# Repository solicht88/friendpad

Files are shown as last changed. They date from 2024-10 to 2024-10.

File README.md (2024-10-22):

# friendpad
My first ever PCB, created for Hack Club's YSWS [Hackpad](https://hackpad.hackclub.com/)!  
Designed to be used for 4 key rhythm games, as well as have enough keys to be used for shortcuts or as a midi controller.  
There was an attempt to make something resembling a friendly face by placing rotary encoders (eyes) on both sides of the OLED (mouth).  
I started this project as a small simple macropad, but then it somehow grew to this

### Acknowledgements:  
[KiCad](https://www.kicad.org/)  
[Shapr3D](https://www.shapr3d.com/)  
[ScottoKeebs Kicad Footprint Collection](https://github.com/joe-scotto/scottokeebs/tree/main/Extras/ScottoKicad)

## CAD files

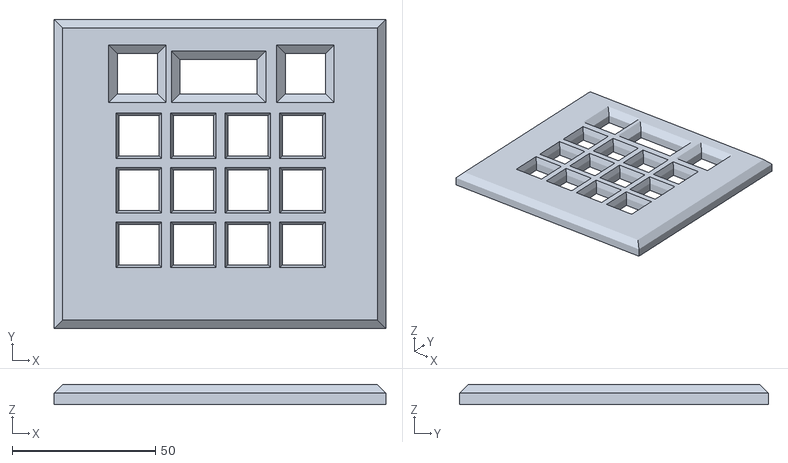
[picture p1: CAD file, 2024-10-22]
cad/case/top_plate.stl
116.0 x 108.0 x 7.00

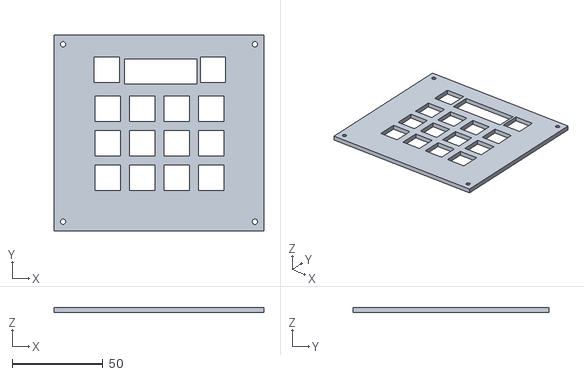
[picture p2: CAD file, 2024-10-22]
cad/case/electronics_plate.stl
116.0 x 108.0 x 3.00

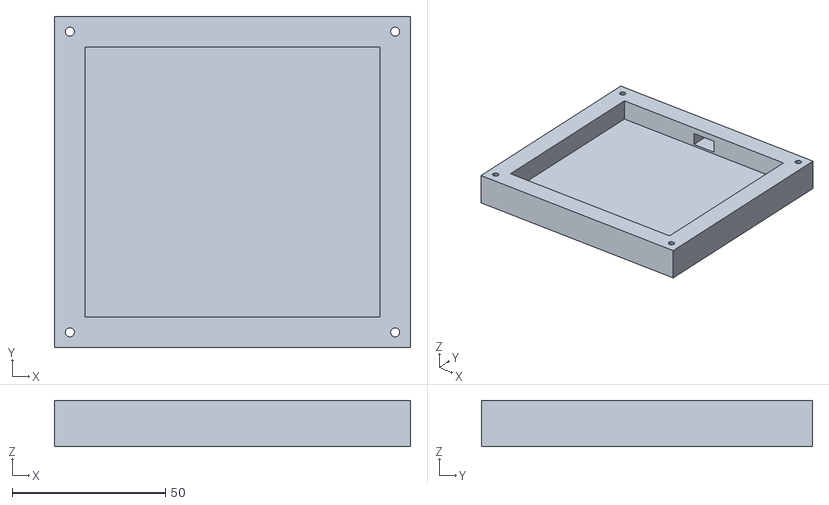
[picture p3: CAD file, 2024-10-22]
cad/case/base.stl
116.0 x 108.0 x 15.0

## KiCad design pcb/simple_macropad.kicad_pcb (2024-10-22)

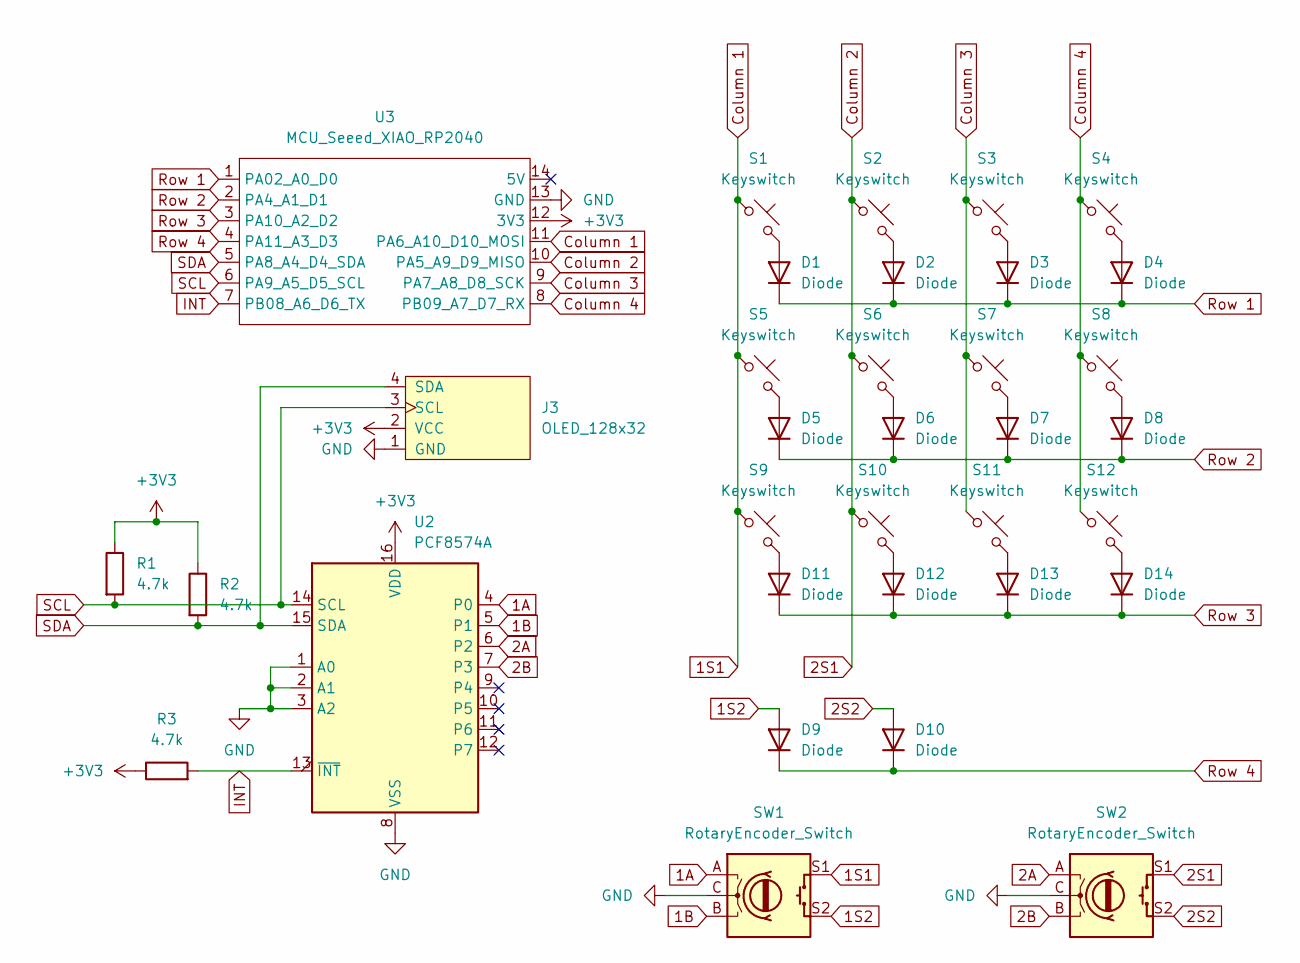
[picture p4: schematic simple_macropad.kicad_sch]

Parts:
D1, D2, D3, D4, D5, D6, D7, D8, D9, D10, D11, D12, D13, D14: Diode; Diode_DO-35
J3: OLED_128x32
R1, R2, R3: 4.7k; R_Axial_DIN0207_L6.3mm_D2.5mm_P10.16mm_Horizontal
S1, S2, S3, S4, S5, S6, S7, S8, S9, S10, S11, S12: Keyswitch; MX_PCB_1.00u
SW1, SW2: RotaryEncoder_Switch; RotaryEncoder_Alps_EC11E-Switch_Vertical_H20mm
U2: PCF8574A; DIP-16_W7.62mm
U3: MCU_Seeed_XIAO_RP2040; Seeed_XIAO_RP2040

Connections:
1A: SW1.A, U2.4 (P0)
1B: SW1.B, U2.5 (P1)
1S1: S1.1, S5.1, S9.1, SW1.S1, U3.11 (PA6_A10_D10_MOSI)
1S2: D9.2 (A), SW1.S2
2A: SW2.A, U2.6 (P2)
2B: SW2.B, U2.7 (P3)
2S1: S2.1, S6.1, S10.1, SW2.S1, U3.10 (PA5_A9_D9_MISO)
2S2: D10.2 (A), SW2.S2
+3V3: J3.2 (VCC), R1.1, R2.1, R3.1, U2.16 (VDD), U3.12 (3V3)
Column 3: S3.1, S7.1, S11.1, U3.9 (PA7_A8_D8_SCK)
Column 4: S4.1, S8.1, S12.1, U3.8 (PB09_A7_D7_RX)
GND: J3.1 (GND), SW1.C, SW2.C, U2.1 (A0), U2.2 (A1), U2.3 (A2), U2.8 (VSS), U3.13 (GND)
INT: R3.2, U2.13 (~INT), U3.7 (PB08_A6_D6_TX)
unnamed: D1.2 (A), S1.2
unnamed: D2.2 (A), S2.2
unnamed: D3.2 (A), S3.2
unnamed: D4.2 (A), S4.2
unnamed: D5.2 (A), S5.2
unnamed: D6.2 (A), S6.2
unnamed: D7.2 (A), S7.2
unnamed: D8.2 (A), S8.2
unnamed: D11.2 (A), S9.2
unnamed: D12.2 (A), S10.2
unnamed: D13.2 (A), S11.2
unnamed: D14.2 (A), S12.2
Row 1: D1.1 (K), D2.1 (K), D3.1 (K), D4.1 (K), U3.1 (PA02_A0_D0)
Row 2: D5.1 (K), D6.1 (K), D7.1 (K), D8.1 (K), U3.2 (PA4_A1_D1)
Row 3: D11.1 (K), D12.1 (K), D13.1 (K), D14.1 (K), U3.3 (PA10_A2_D2)
Row 4: D9.1 (K), D10.1 (K), U3.4 (PA11_A3_D3)
SCL: J3.3 (SCL), R1.2, U2.14 (SCL), U3.6 (PA9_A5_D5_SCL)
SDA: J3.4 (SDA), R2.2, U2.15 (SDA), U3.5 (PA8_A4_D4_SDA)

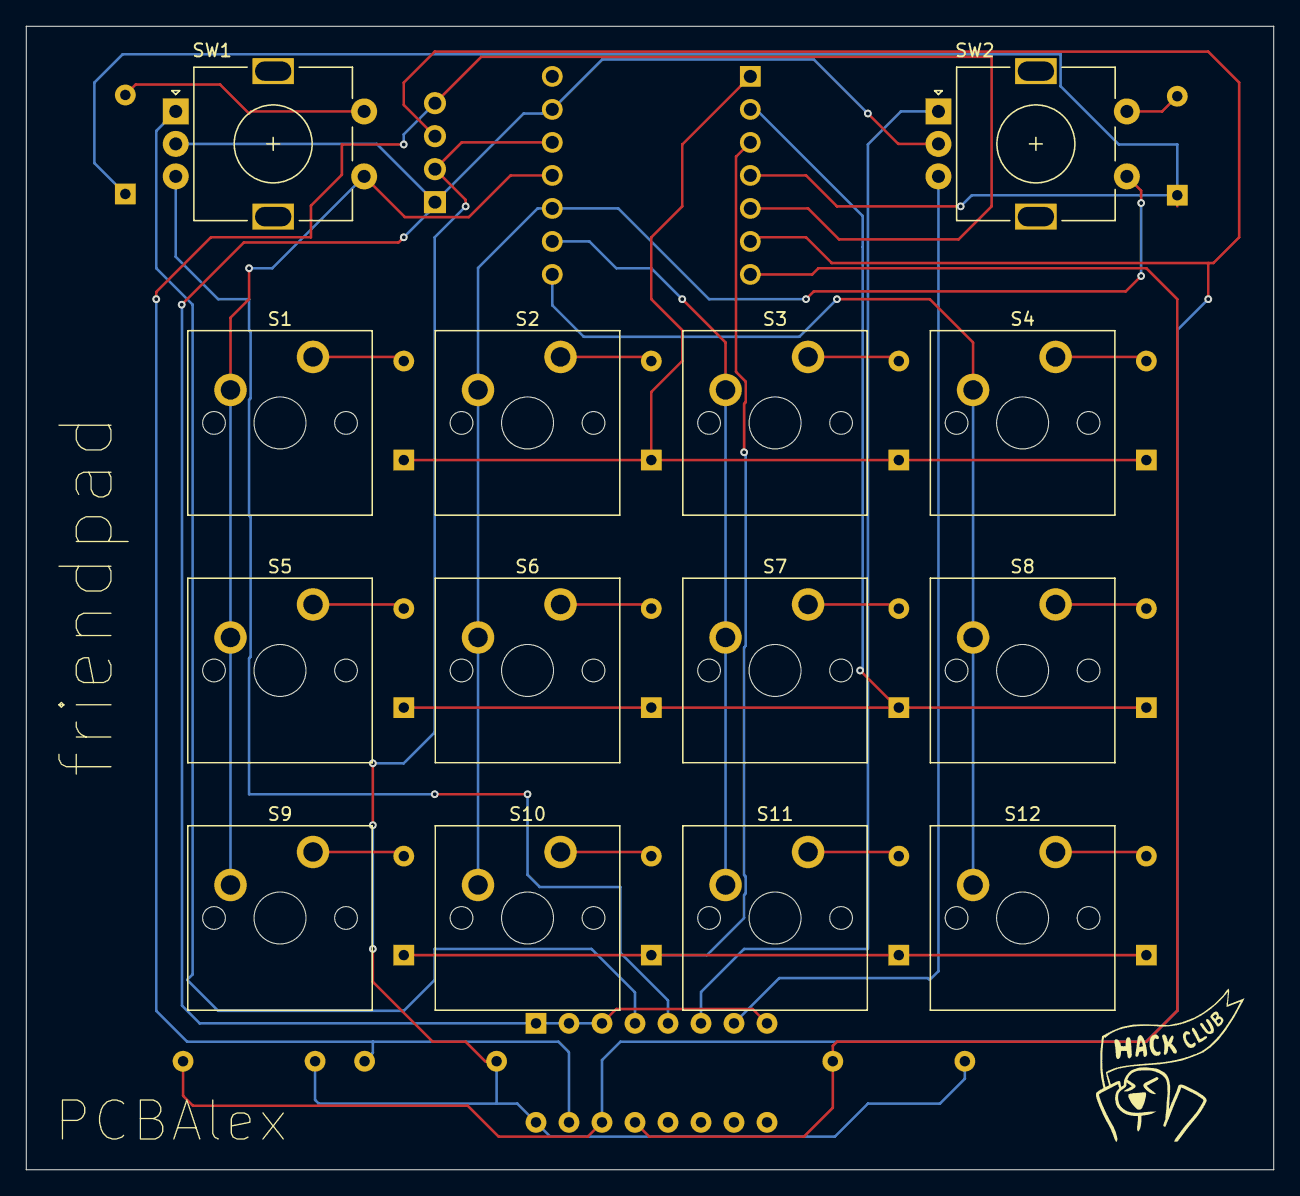
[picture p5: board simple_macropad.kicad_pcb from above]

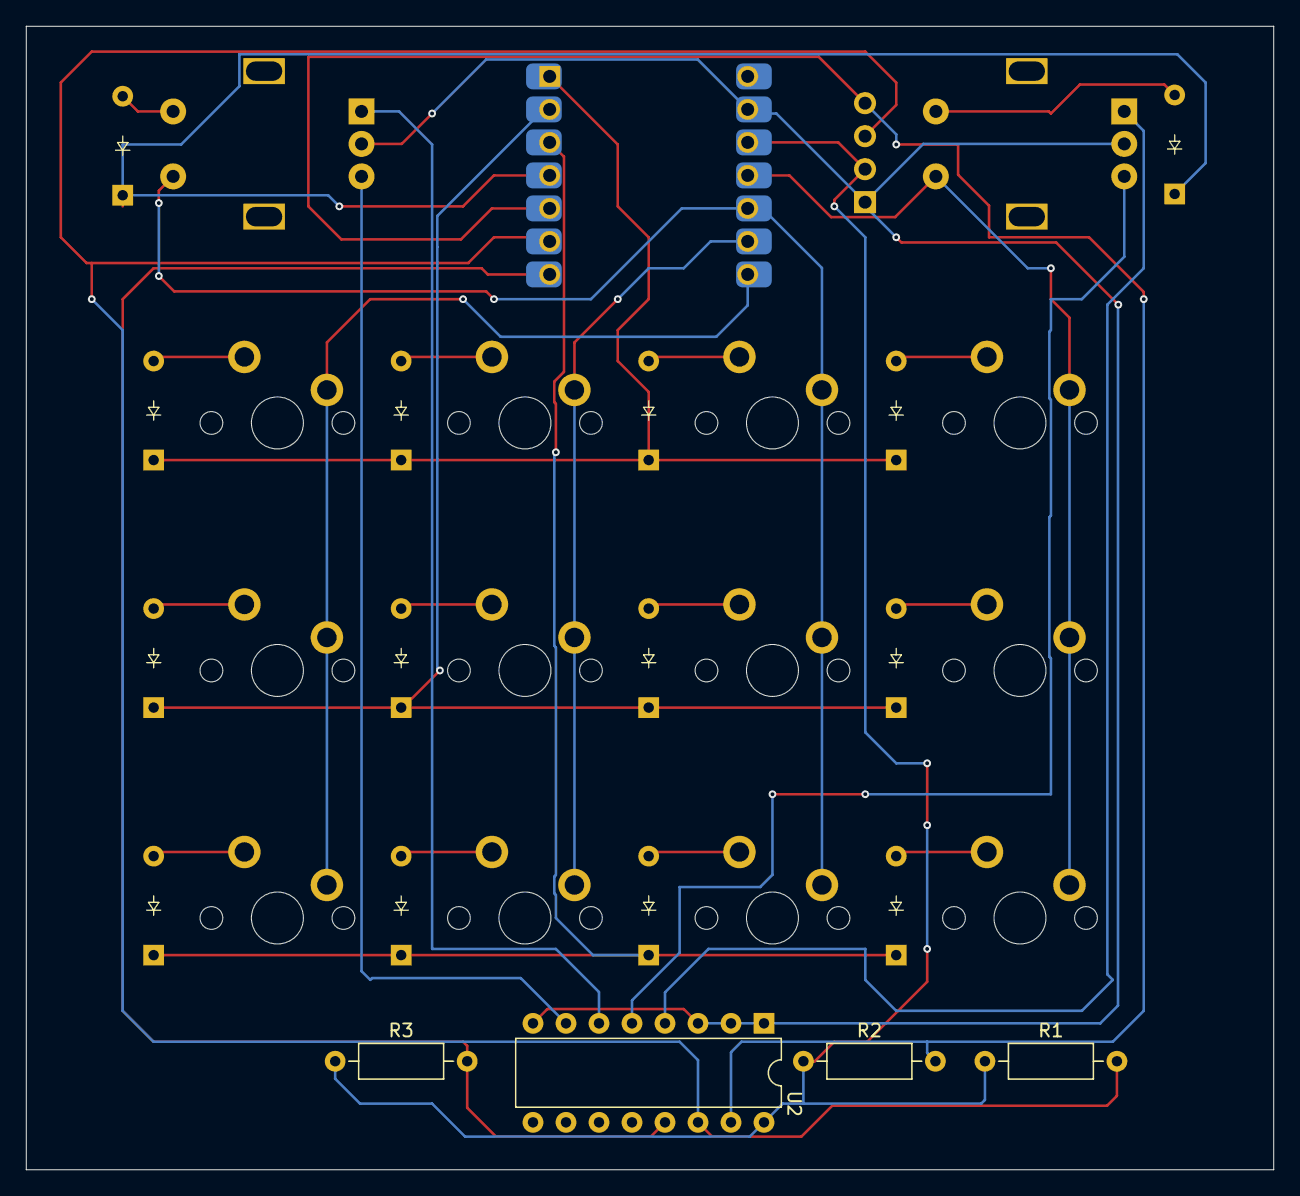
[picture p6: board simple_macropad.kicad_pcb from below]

Board: 2 copper layers, 96.0 x 88.0 mm, 35 parts (19 on the bottom side), 31 nets.

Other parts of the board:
 : LOGO

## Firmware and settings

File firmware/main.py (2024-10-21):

print("Hello world!")

import board
import busio

from kmk.kmk_keyboard import KMKKeyboard
from kmk.keys import KC
from kmk.scanners import DiodeOrientation
from kmk.extensions.adafruit.pcf8574 import PCF8574

# encoder imports
from kmk.modules.encoder import EncoderHandler

# display imports
from kmk.extensions.display.ssd1306 import SSD1306
from kmk.extensions.display import Display, TextEntry, ImageEntry

keyboard = KMKKeyboard()

i2c_bus = busio.I2C(board.GP_SCL, board.GP_SDA)
driver = SSD1306(
    i2c=i2c_bus,
    device_address=0x3C,
)

expander = PCF8574(board.I2C(), address=0x38)

# matrix pins
keyboard.col_pins = (board.D10, board.D9, board.D8, board.D7)
keyboard.row_pins = (board.D0, board.D1, board.D2, board.D3)

keyboard.diode_orientation = DiodeOrientation.COL2ROW

# rotary encoders
encoder_handler = EncoderHandler()
keyboard.modules.append(encoder_handler)
SDA = board.D4
SCL = board.D5
i2c = busio.I2C(SCL, SDA)
encoder_handler.pins = (
    (expander.get_pin(0), expander.get_pin(1), None, False,),
    (expander.get_pin(2), expander.get_pin(3), None, False,),
)
encoder_handler.map = (
    ((KC.VOLD, KC.VOLU, None),
     (KC.LCTRL(KC.MINUS), KC.LCTRL(KC.EQUAL), None),),
)

# OLED
display = Display(
    display = driver,
    entries = [
        TextEntry(text=":)", x=0, y=0, x_anchor="M", y_anchor="M")
    ]
    width=128,
    height=32,
    dim_time=30,
    dim_target=0.2,
    off_time=300,
    brightness=1
)
keyboard.extensions.append(display)

# keymap
keyboard.keymap = [
    [KC.LCTRL(KC.C), KC.LCTRL(KC.V), KC.ENTER, KC.BSPC],
    [KC.B, KC.E, KC.LCTRL(KC.Z), KC.LCTRL(KC.LSHIFT(KC.Y))],
    [KC.D, KC.F, KC.J, KC.K],
    [KC.MUTE, KC.N1, KC.NO, KC.NO]
]

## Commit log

2024-10-08 created keyswitch matrix
    [simple_macropad.kicad_pcb, simple_macropad.kicad_sch]
2024-10-18 added footprints
    [simple_macropad.kicad_sch]
2024-10-20 wired components in pcb
    [simple_macropad.kicad_pcb, simple_macropad.kicad_sch]
2024-10-20 completed case stl files
    [base.stl, electronics_plate.stl, top_plate.stl]
2024-10-21 updated pcb silkscreen
    [simple_macropad.kicad_pcb]
2024-10-22 update readme, bom, and cad
    [base.stl, electronics_plate.stl, top_plate.stl]
2024-10-22 created gerbers.zip, updated .stl files
    [base.stl, electronics_plate.stl, simple_macropad.kicad_pcb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]
